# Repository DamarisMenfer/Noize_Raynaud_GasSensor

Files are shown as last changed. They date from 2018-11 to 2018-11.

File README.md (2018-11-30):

# MOSH
#### Arduino Project in 5th year ISS at INSA Toulouse

## Overview
This repository contains the work produced during the course of Microcontroler and Open-Source Hardware (MOSH) of the 5th year Innovative Smart Systems (ISS) at INSA Toulouse. This work was produced by Alex Noize and Mathieu Raynaud.

The aim of this project was to design a complete PCB (Printed Circuit Board) implementing a double layer transimpedance amplificator assembly. This circuit is then used plugged to an Arduino board and a LoRa antenna to collect data from a gaz sensor and send it through a LoRa network.

## Project location
The project is located [here](https://github.com/AlexNoize/MOSH/tree/master/KiCad/Shield_Gas_Sensor/Shield_Gas_Sensor_Final).

## PCB schematic
Let's first have a look to the electrical circuit:

Electrical scheme

On the center of the image, the double layer transimpedance circuit implements several functionalities: 
* On the left of the scheme, the entry resistor (R1) protect the operational amplifier from the electrostatic discharges, and is associated to the C1 capacitor to filter the voltage noise.
* The C1 capacitor is also associated to the R2 resistor to filter the current noise.
* The R3 resistor is used to adapt our assembly to the correct calibre.
* At the output of the amplifier, the C2 capacitor is associated to the R4 resistor to create an active filter.
* Then, the R5 resistor and the C4 capacitor constitute a low-pass filter at the output of the assembly.
* Finally, the C3 capacitor filter the noise coming from the 5V voltage input.

We also have 3 other schemes on the picture which are:
* The RN2483 LoRa transceiver scheme on the left-top of the scheme
* The gas sensor scheme on the top of the scheme
* The Arduino Uno shield schematic on the right of the scheme
These components are required on the scheme because they need to be considered as soon as our PCB needs to communicate with them.

## PCB footprint on KiCad
Now, let's study the footprint generated with KiCad:

PCB footprint

On the footprint above, we made the connections between all the needed pins of our board.

To be able to put our routes on only one face of the PCB, we had to add a ground layer on the entire surface of the PCB, so that we didn't need anymore to connect the ground-connected pins each others. This was also done for economical purposes.

Finally, we can see that two pairs of pins are still not connected on the footprint. In fact, these are two pairs of pins which are directly connected to the Arduino, and they have the same potential but they are already connected through the Arduino Uno.

## PCB 3D view
Finally, here are the generated 3D views for our PCB:

PCB foreground 3D view

PCB background 3D view

## Conclusion
The knowledge acquired during our courses allowed us to create with KiCad a PCB able to be plugged on an Arduino Uno, and to receive a gas sensor and a LoRa transceiver.

Now the next step is the print of the PCB and the creation of the gas sensor to implement the complete system.

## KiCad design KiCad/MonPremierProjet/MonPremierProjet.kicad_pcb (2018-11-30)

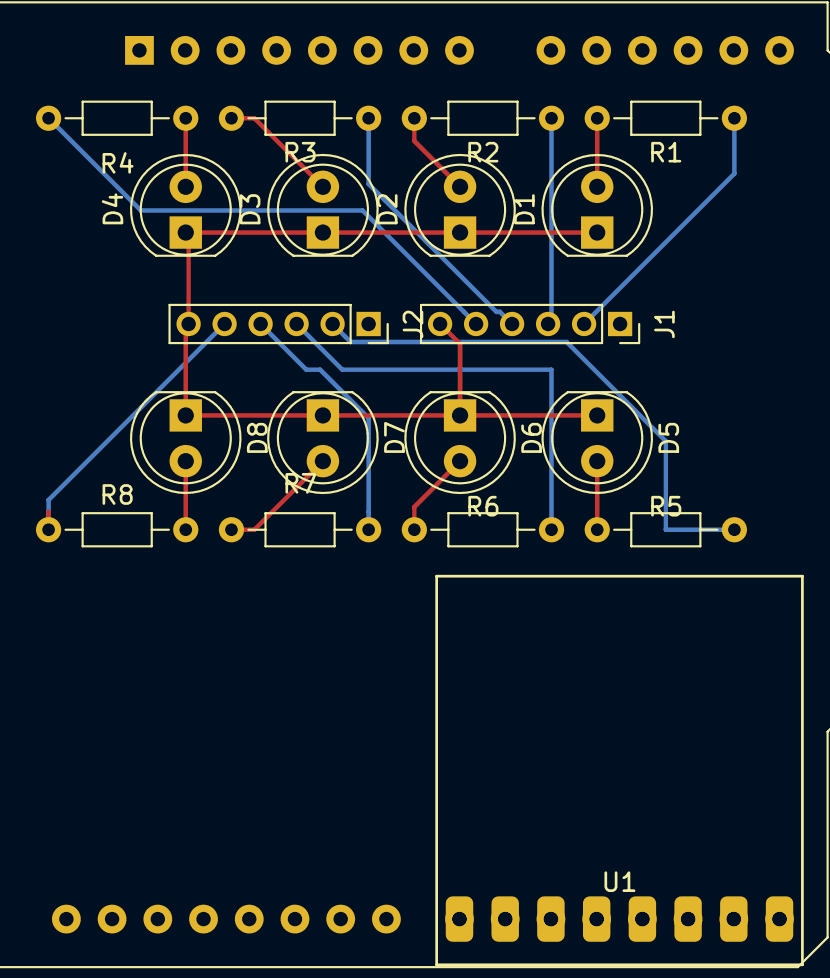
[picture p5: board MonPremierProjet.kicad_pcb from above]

Board: 2 copper layers, 20 parts (0 on the bottom side), 18 nets.

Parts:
A1: Arduino_UNO_R2
D1, D2, D3, D4, D5, D6, D7, D8: LED; LED_D5.0mm_FlatTop
J1, J2: Conn_01x06; PinSocket_1x06_P2.00mm_Vertical
R1, R2, R3, R4, R5, R6, R7, R8: R; R_Axial_DIN0204_L3.6mm_D1.6mm_P7.62mm_Horizontal
U1: RN2483_Breakout; Rn2483 Breakout

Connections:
/CMD_LED1: J1.2, R1.1
/CMD_LED2: J1.3, R2.1
/CMD_LED3: J1.4, R3.1
/CMD_LED4: J1.5, R4.1
/CMD_LED5: J2.2, R5.1
/CMD_LED6: J2.3, R6.1
/CMD_LED7: J2.4, R7.1
/CMD_LED8: J2.5, R8.1
GND: D1.1, D2.1, D3.1, D4.1, D5.1, D6.1, D7.1, D8.1, J1.6, J2.6
unnamed: D1.2, R1.2
unnamed: D2.2, R2.2
unnamed: D3.2, R3.2
unnamed: D4.2, R4.2
unnamed: D5.2, R5.2
unnamed: D6.2, R6.2
unnamed: D7.2, R7.2
unnamed: D8.2, R8.2
VCC: J1.1, J2.1

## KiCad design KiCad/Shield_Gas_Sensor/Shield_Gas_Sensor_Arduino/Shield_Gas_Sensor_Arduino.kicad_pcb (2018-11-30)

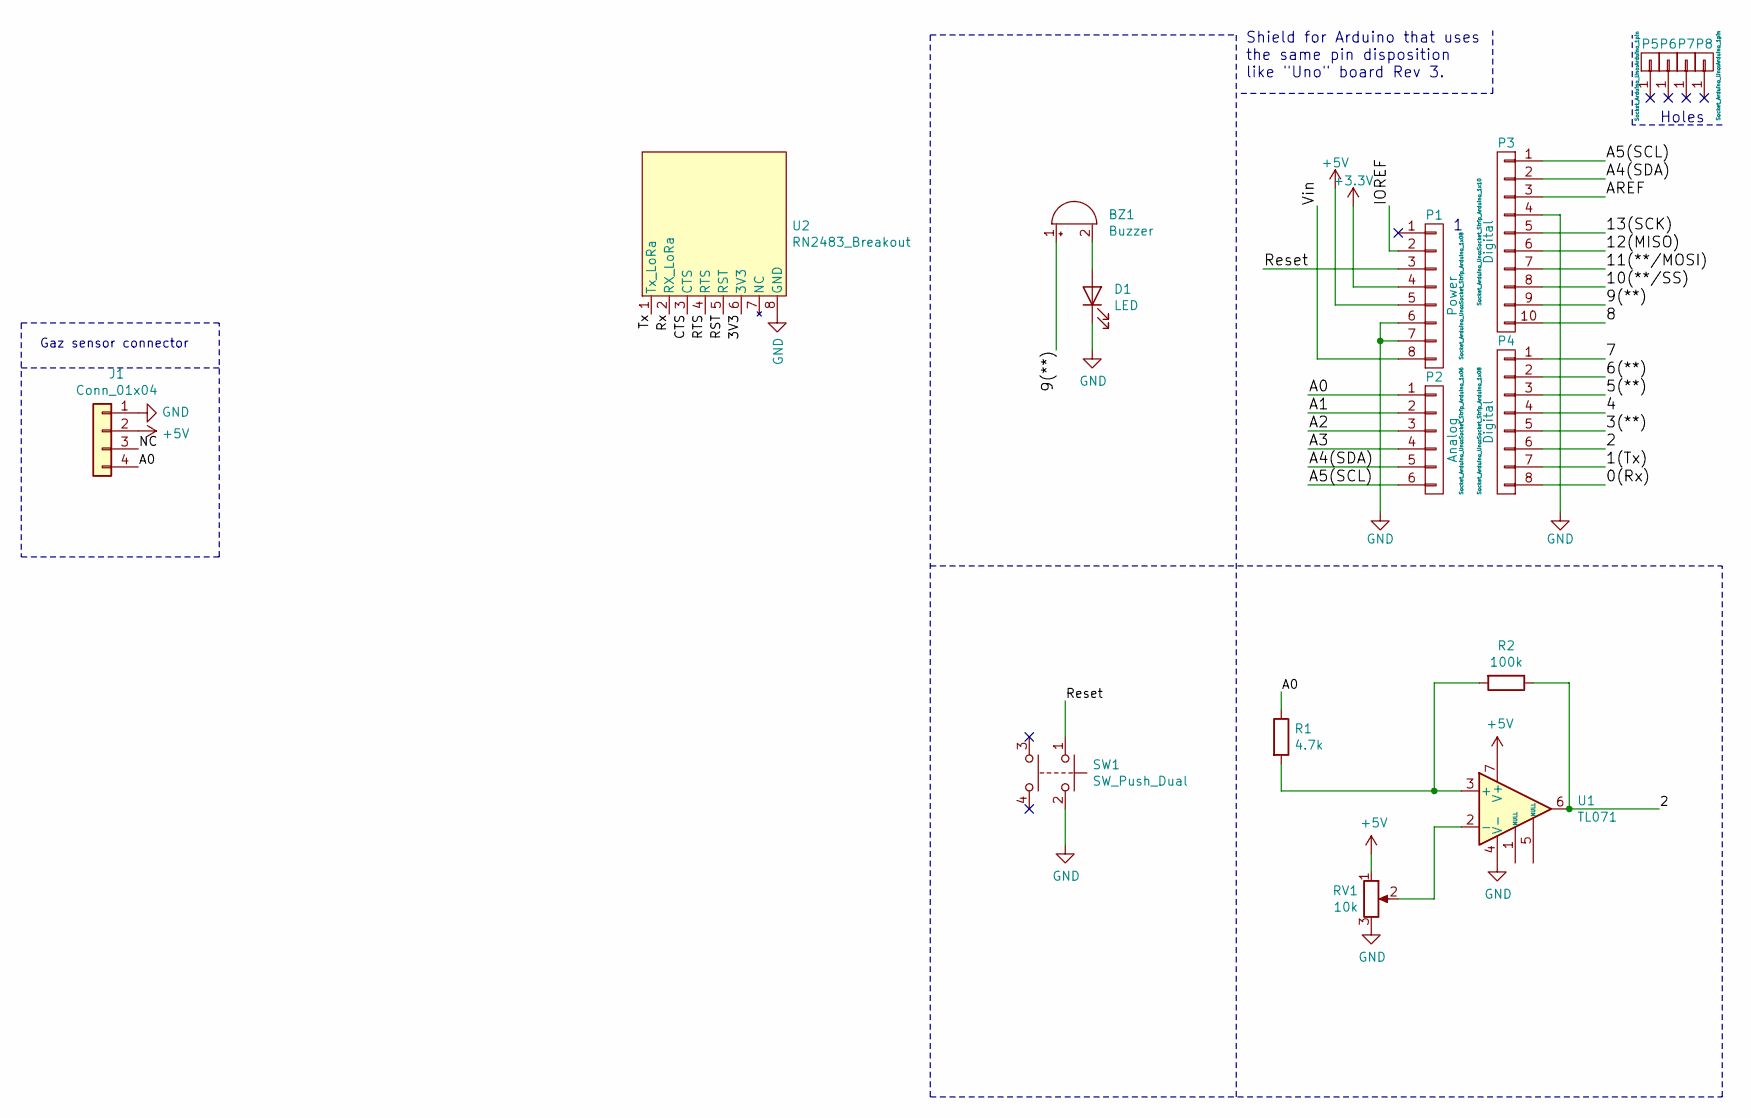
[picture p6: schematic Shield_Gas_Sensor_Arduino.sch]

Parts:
BZ1: Buzzer; Buzzer_12x9.5RM7.6
D1: LED; LED_D5.0mm_IRGrey
J1: Conn_01x04; JST_PH_B4B-PH-K_1x04_P2.00mm_Vertical
P1: Power; Socket_Strip_Arduino_1x08
P2: Analog; Socket_Strip_Arduino_1x06
P3: Digital; Socket_Strip_Arduino_1x10
P4: Digital; Socket_Strip_Arduino_1x08
P5, P6, P7, P8: CONN_01X01; Arduino_1pin
R1: 4.7k; R_Axial_DIN0204_L3.6mm_D1.6mm_P7.62mm_Horizontal
R2: 100k; R_Axial_DIN0204_L3.6mm_D1.6mm_P7.62mm_Horizontal
RV1: 10k; Potentiometer_ACP_CA9-V10_Vertical
SW1: SW_Push_Dual; SW_TH_Tactile_Omron_B3F-10xx
U1: TL071; TE_1-2199298-2
U2: RN2483_Breakout; Module_RN2483_Breakout

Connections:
+3V3: P1.4
+5V: J1.2, P1.5, RV1.1, U1.7 (V+)
/0(Rx): P4.8
/1(Tx): P4.7
/2: P4.6, R2.1, U1.6
/3(**): P4.5
/3V3: U2.6 (3V3)
/4: P4.4
/5(**): P4.3
/6(**): P4.2
/7: P4.1
/8: P3.10
/9(**): BZ1.1 (-), P3.9
/10(**/SS): P3.8
/11(**/MOSI): P3.7
/12(MISO): P3.6
/13(SCK): P3.5
/A0: J1.4, P2.1, R1.1
/A1: P2.2
/A2: P2.3
/A3: P2.4
/A4(SDA): P2.5, P3.2
/A5(SCL): P2.6, P3.1
/AREF: P3.3
/CTS: U2.3 (CTS)
/IOREF: P1.2
/NC: J1.3
/RST: U2.5 (RST)
/RTS: U2.4 (RTS)
/Reset: P1.3, SW1.1
/Rx: U2.2 (RX_LoRa)
/Tx: U2.1 (Tx_LoRa)
/Vin: P1.8
GND: D1.1 (K), J1.1, P1.6, P1.7, P3.4, RV1.3, SW1.2, U1.4 (V-), U2.8 (GND)
unnamed: BZ1.2 (+), D1.2 (A)
unnamed: R1.2, R2.2, U1.3 (+)
unnamed: RV1.2, U1.2 (-)

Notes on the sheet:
Holes
Shield for Arduino that uses the same pin disposition like "Uno" board Rev 3.
Gaz sensor connector

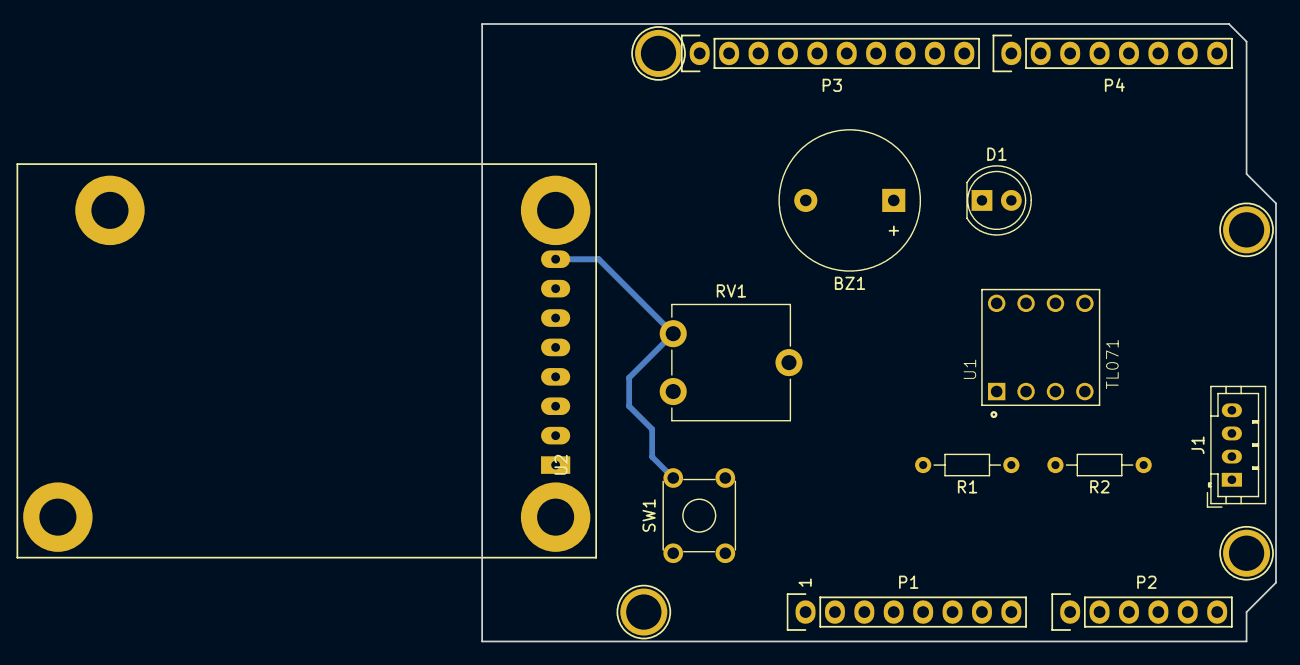
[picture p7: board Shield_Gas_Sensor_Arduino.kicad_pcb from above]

Board: 2 copper layers, 68.6 x 53.3 mm, 17 parts (0 on the bottom side), 11 nets.

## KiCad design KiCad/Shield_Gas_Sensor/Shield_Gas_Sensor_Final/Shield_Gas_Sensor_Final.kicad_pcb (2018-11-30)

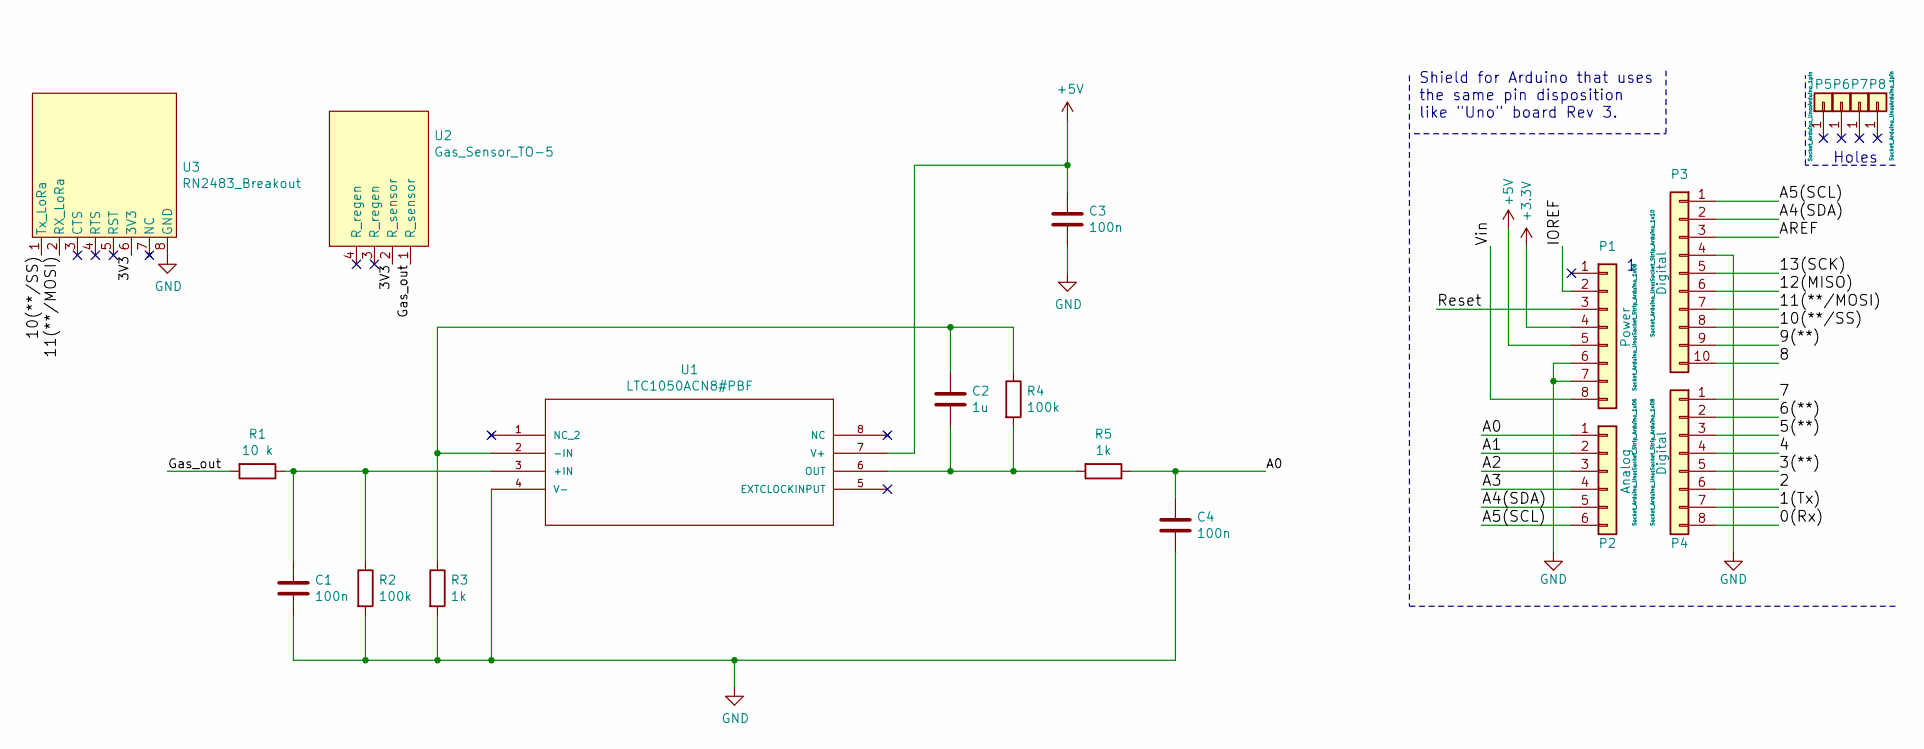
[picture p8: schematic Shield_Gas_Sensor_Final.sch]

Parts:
C1, C3, C4: 100n; CP_Radial_Tantal_D5.0mm_P5.00mm
C2: 1u; CP_Radial_Tantal_D5.0mm_P5.00mm
P1: Power; Socket_Strip_Arduino_1x08
P2: Analog; Socket_Strip_Arduino_1x06
P3: Digital; Socket_Strip_Arduino_1x10
P4: Digital; Socket_Strip_Arduino_1x08
P5, P6, P7, P8: CONN_01X01; Arduino_1pin
R1: 10 k; R_Axial_DIN0204_L3.6mm_D1.6mm_P5.08mm_Horizontal
R2, R4: 100k; R_Axial_DIN0204_L3.6mm_D1.6mm_P5.08mm_Horizontal
R3, R5: 1k; R_Axial_DIN0204_L3.6mm_D1.6mm_P5.08mm_Horizontal
U1: LTC1050ACN8#PBF; DIP-8_W7.62mm_LongPads
U2: Gas_Sensor_TO-5; Gas_Sensor_TO-5-4
U3: RN2483_Breakout; Module_RN2483_Breakout

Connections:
+3V3: P1.4
+5V: C3.1, P1.5, U1.7 (V+)
/0(Rx): P4.8
/1(Tx): P4.7
/2: P4.6
/3(**): P4.5
/3V3: U2.2 (R_sensor), U3.6 (3V3)
/4: P4.4
/5(**): P4.3
/6(**): P4.2
/7: P4.1
/8: P3.10
/9(**): P3.9
/10(**/SS): P3.8, U3.1 (Tx_LoRa)
/11(**/MOSI): P3.7, U3.2 (RX_LoRa)
/12(MISO): P3.6
/13(SCK): P3.5
/A0: C4.1, P2.1, R5.1
/A1: P2.2
/A2: P2.3
/A3: P2.4
/A4(SDA): P2.5, P3.2
/A5(SCL): P2.6, P3.1
/AREF: P3.3
/Gas_out: R1.2, U2.1 (R_sensor)
/IOREF: P1.2
/Reset: P1.3
/Vin: P1.8
GND: C1.2, C3.2, C4.2, P1.6, P1.7, P3.4, R2.2, R3.2, U1.4 (V-), U3.8 (GND)
unnamed: C1.1, R1.1, R2.1, U1.3 (+IN)
unnamed: C2.1, R3.1, R4.1, U1.2 (-IN)
unnamed: C2.2, R4.2, R5.2, U1.6 (OUT)

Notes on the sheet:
Holes
Shield for Arduino that uses the same pin disposition like "Uno" board Rev 3.

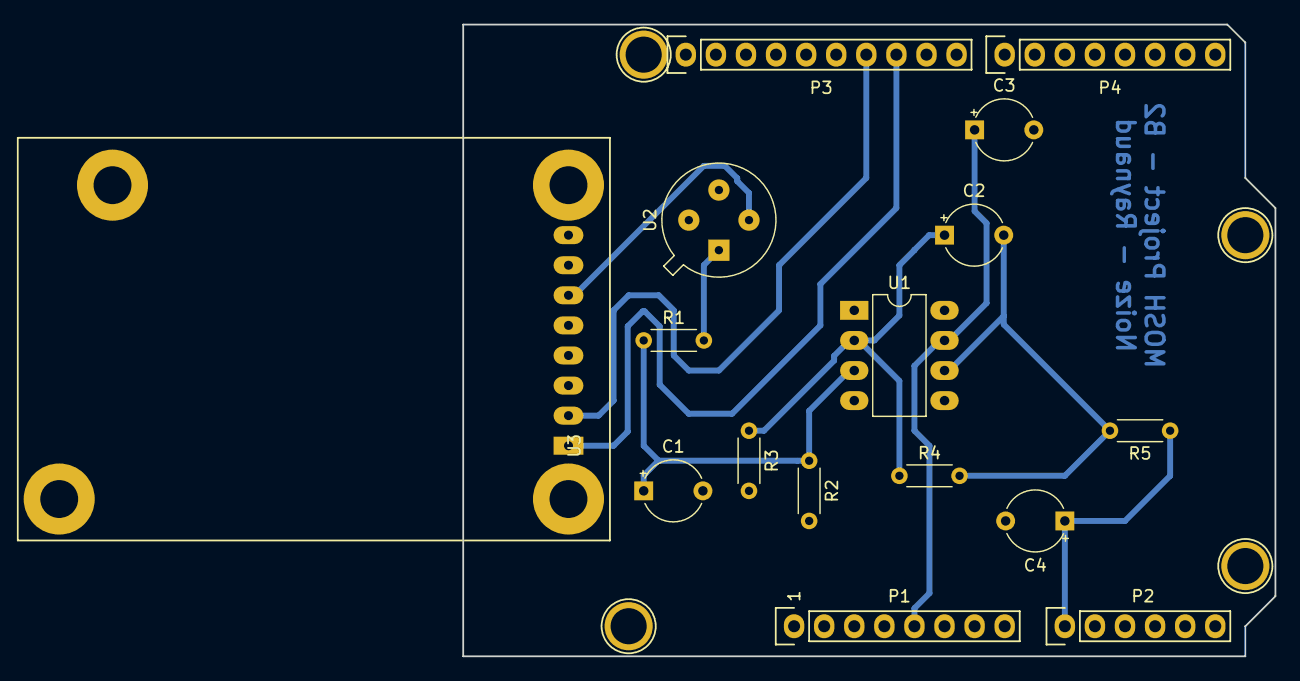
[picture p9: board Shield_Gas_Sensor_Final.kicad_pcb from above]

Board: 2 copper layers, 68.6 x 53.3 mm, 20 parts (0 on the bottom side), 12 nets.

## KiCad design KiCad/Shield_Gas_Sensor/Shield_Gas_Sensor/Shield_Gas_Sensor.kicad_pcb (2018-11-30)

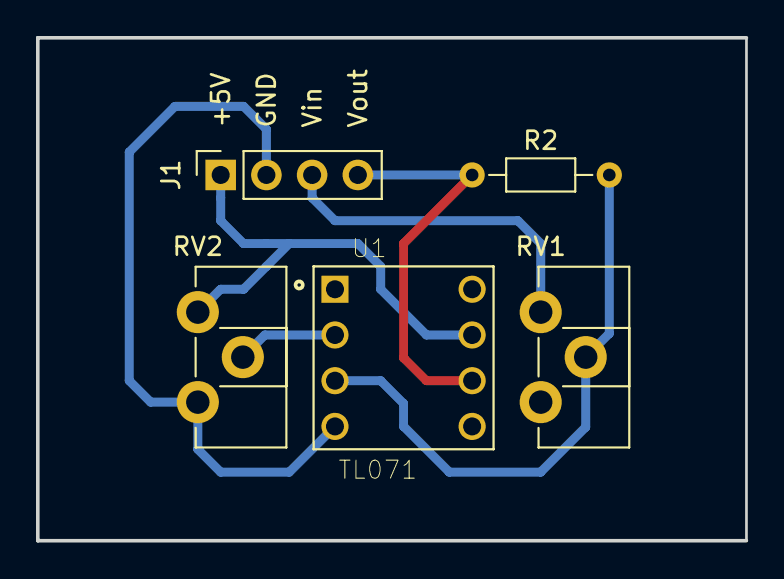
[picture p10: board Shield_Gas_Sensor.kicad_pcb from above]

Board: 2 copper layers, 39.4 x 27.9 mm, 5 parts (0 on the bottom side), 6 nets.

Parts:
J1: Conn_01x04_Female; PinSocket_1x04_P2.54mm_Vertical
R2: 10k; R_Axial_DIN0204_L3.6mm_D1.6mm_P7.62mm_Horizontal
RV1, RV2: 10k; Potentiometer_ACP_CA9-H2,5_Horizontal
U1: TL071; TE_1-2199298-2

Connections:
+5V: J1.1, RV2.1, U1.7
/Vin: J1.3, RV1.1
/Vout: J1.4, R2.1, U1.6
/Vref: RV2.2, U1.2
GND: J1.2, RV1.3, RV2.3, U1.4
unnamed: R2.2, RV1.2, U1.3

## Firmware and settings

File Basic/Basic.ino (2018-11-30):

#include <TheThingsNode.h>
#include <SoftwareSerial.h>


SoftwareSerial loraSerial(3,2);

// Set your AppEUI and AppKey
const char *appEui = "70B3D57ED0012EC6";
const char *appKey = "475FF2D479B785278A5A4C8B5C298CD2";


#define debugSerial Serial

// Replace REPLACE_ME with TTN_FP_EU868 or TTN_FP_US915
#define freqPlan TTN_FP_EU868

TheThingsNetwork ttn(loraSerial, debugSerial, freqPlan);
TheThingsNode *node;

#define PORT_SETUP 1
#define PORT_INTERVAL 2
#define PORT_MOTION 3
#define PORT_BUTTON 4

/*
Decoder payload function
------------------------

function Decoder(bytes, port) {
  var decoded = {};
  var events = {
    1: 'setup',
    2: 'interval',
    3: 'motion',
    4: 'button'
  };
  decoded.event = events[port];
  decoded.battery = (bytes[0] << 8) + bytes[1];
  decoded.light = (bytes[2] << 8) + bytes[3];
  if (bytes[4] & 0x80)
    decoded.temperature = ((0xffff << 16) + (bytes[4] << 8) + bytes[5]) / 100;
  else
    decoded.temperature = ((bytes[4] << 8) + bytes[5]) / 100;
  return decoded;
}
*/

void setup()
{
  loraSerial.begin(57600);
  debugSerial.begin(9600);

  // Wait a maximum of 10s for Serial Monitor
  while (!debugSerial && millis() < 10000)
    ;

  // Config Node
  node = TheThingsNode::setup();
  node->configLight(true);
  node->configInterval(true, 60000);
  node->configTemperature(true);
  node->onWake(wake);
  node->onInterval(interval);
  node->onSleep(sleep);
  node->onMotionStart(onMotionStart);
  node->onButtonRelease(onButtonRelease);

  // Test sensors and set LED to GREEN if it works
  node->showStatus();
  node->setColor(TTN_GREEN);

  debugSerial.println("-- TTN: STATUS");
  ttn.showStatus();

  debugSerial.println("-- TTN: JOIN");
  ttn.join(appEui, appKey);

  debugSerial.println("-- SEND: SETUP");
  sendData(PORT_SETUP);
}

void loop()
{
  node->loop();
}

void interval()
{
  node->setColor(TTN_BLUE);

  debugSerial.println("-- SEND: INTERVAL");
  sendData(PORT_INTERVAL);
}

void wake()
{
  node->setColor(TTN_GREEN);
}

void sleep()
{
  node->setColor(TTN_BLACK);
}

void onMotionStart()
{
  node->setColor(TTN_BLUE);

  debugSerial.print("-- SEND: MOTION");
  sendData(PORT_MOTION);
}

void onButtonRelease(unsigned long duration)
{
  node->setColor(TTN_BLUE);

  debugSerial.print("-- SEND: BUTTON");
  debugSerial.println(duration);

  sendData(PORT_BUTTON);
}

void sendData(uint8_t port)
{
  // Wake RN2483
  ttn.wake();

  ttn.showStatus();
  node->showStatus();

  byte *bytes;
  byte payload[6];

  uint16_t battery = node->getBattery();
  bytes = (byte *)&battery;
  payload[0] = bytes[1];
  payload[1] = bytes[0];

  uint16_t light = node->getLight();
  bytes = (byte *)&light;
  payload[2] = bytes[1];
  payload[3] = bytes[0];

  int16_t temperature = round(node->getTemperatureAsFloat() * 100);
  bytes = (byte *)&temperature;
  payload[4] = bytes[1];
  payload[5] = bytes[0];

  ttn.sendBytes(payload, sizeof(payload), port);

  // Set RN2483 to sleep mode
  ttn.sleep(60000);

  // This one is not optionnal, remove it
  // and say bye bye to RN2983 sleep mode
  delay(50);
}

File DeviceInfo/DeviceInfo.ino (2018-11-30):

#include <TheThingsNetwork.h>
#include <SoftwareSerial.h>


SoftwareSerial loraSerial(10,11); //RX,TX
#define debugSerial Serial

// Replace REPLACE_ME with TTN_FP_EU868 or TTN_FP_US915
#define freqPlan TTN_FP_EU868

TheThingsNetwork ttn(loraSerial, debugSerial, freqPlan);

void setup()
{
  loraSerial.begin(57600);
  debugSerial.begin(9600);
}

void loop()
{
  debugSerial.println("Device Information");
  debugSerial.println();
  ttn.showStatus();
  debugSerial.println();
  debugSerial.println("Use the EUI to register the device for OTAA");
  debugSerial.println("-------------------------------------------");
  debugSerial.println();

  delay(10000);
}
